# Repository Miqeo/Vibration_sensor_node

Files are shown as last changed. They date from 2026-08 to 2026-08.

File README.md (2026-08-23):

# Vibration sensor node

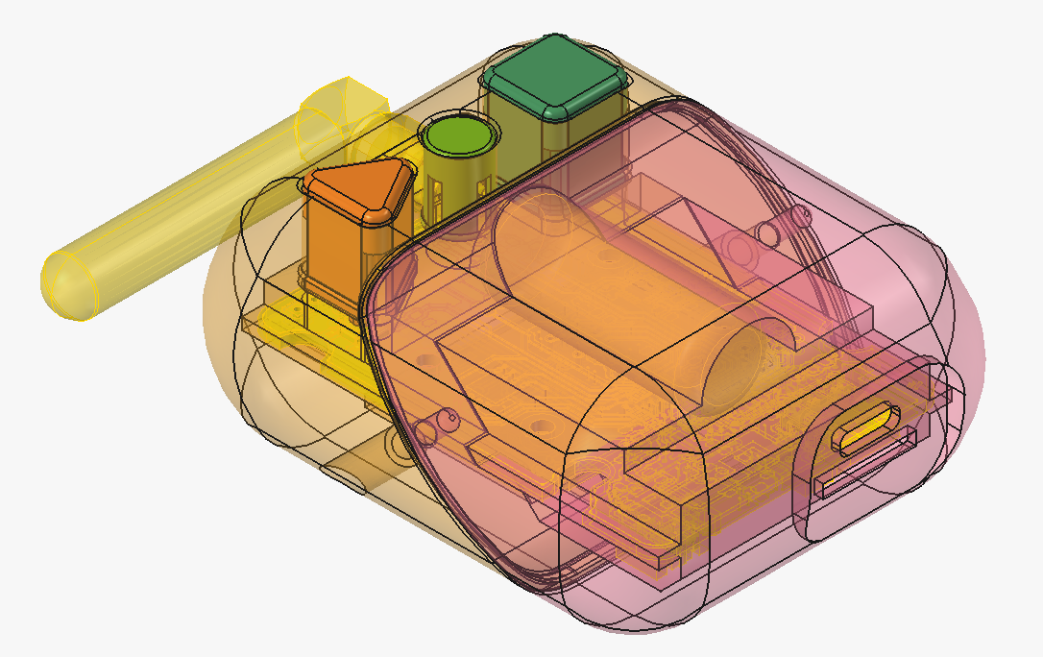
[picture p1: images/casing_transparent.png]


## Motivation

Since my first endeavour into PCB and CAD design, I have always wanted to create something from start to finish. This was possible with one of the previous projects I was a part of, where there was a need to make a Raspberry Pi HAT, the software to run with it, and the corresponding casing.

As that project came to a close, I wanted to make use of my time and extend my knowledge with this initiative to make something useful and to test the capabilities of FOSS software such as Freecad and Kicad.

This culminated in the amalgamation of sensors, storage, comms, and compute that can be called a “node” for the distributed sensor system.

As this is a work in progress, and the exact use might change with time, I do not want to point towards the problem it might, in the future, solve. The time-synchronised system of this kind may be used in places where other, physically connected or remote nodes are used now.

## Future capabilities

The planned capabilities of the node are to autonomously save vibration data and synchronize it in time with other nodes using a wireless link. The nodes equipped with the 3-axis gyroscope would also be able to track changes in rotation. 

## System elements

The system makes use of the small cyllindrical battery, repurposed from an ellectrical cigarette. The main computation is done by the STM32 microcontroller, which has access to the onboard accrellerometer-gyroscope combo and an extensible accelerometer via a board-to-board connector. The microcontroller is connected to the outside world via the wireless module and usb 2.0 via USB-C, which also acts as the charger for the unit. The data collected can be stored on the external SD card or the soldered-on QSPI flash.

[Here is the schematic document of the controller board](/pcb/accel_controller_schematic.pdf)

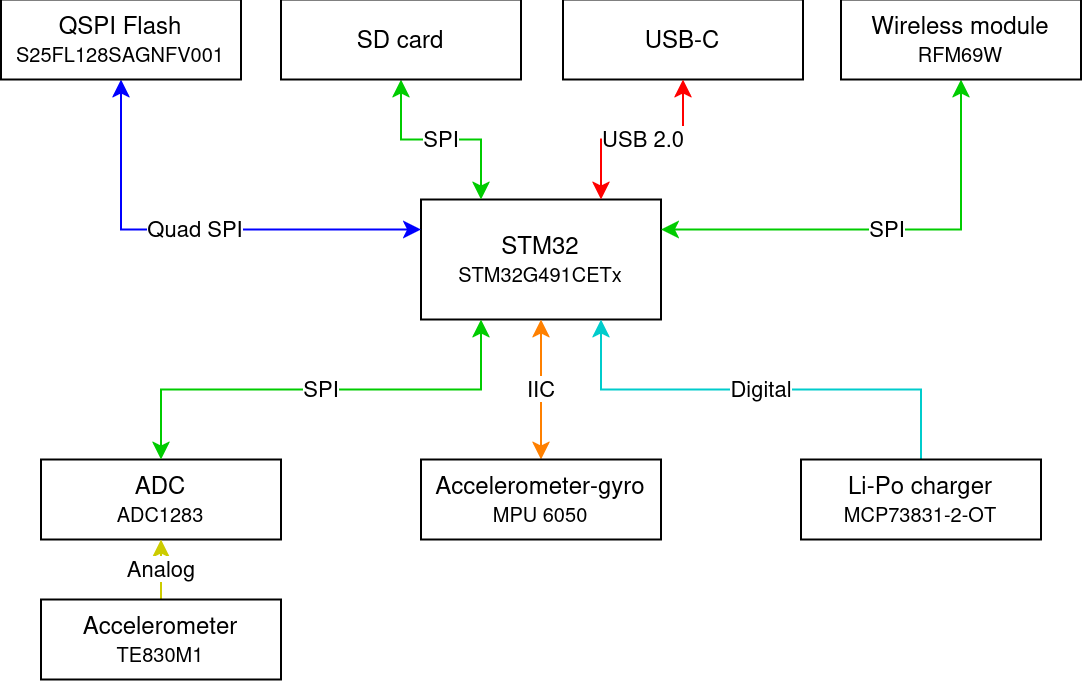
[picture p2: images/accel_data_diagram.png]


*Data flow of the system*

## Fabrication

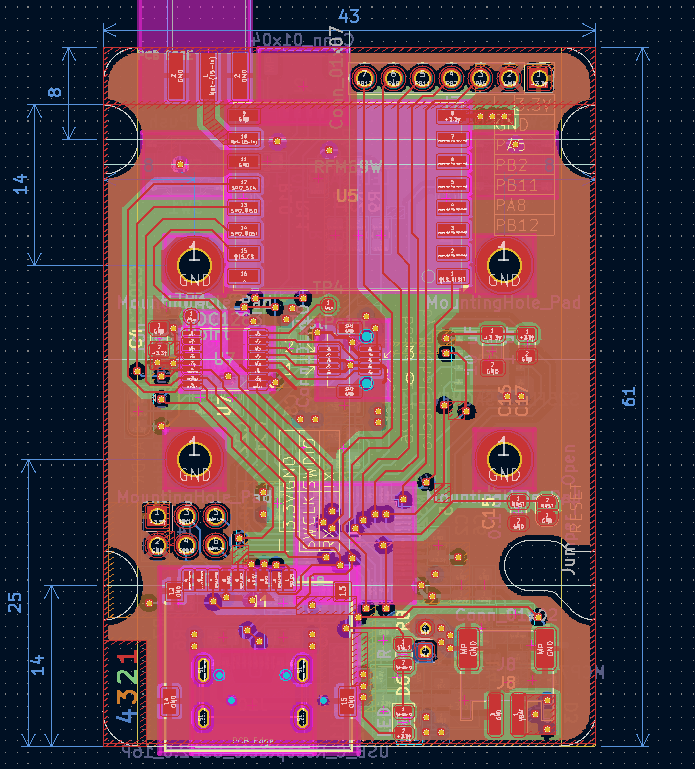
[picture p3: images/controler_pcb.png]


*The main controller PCB*

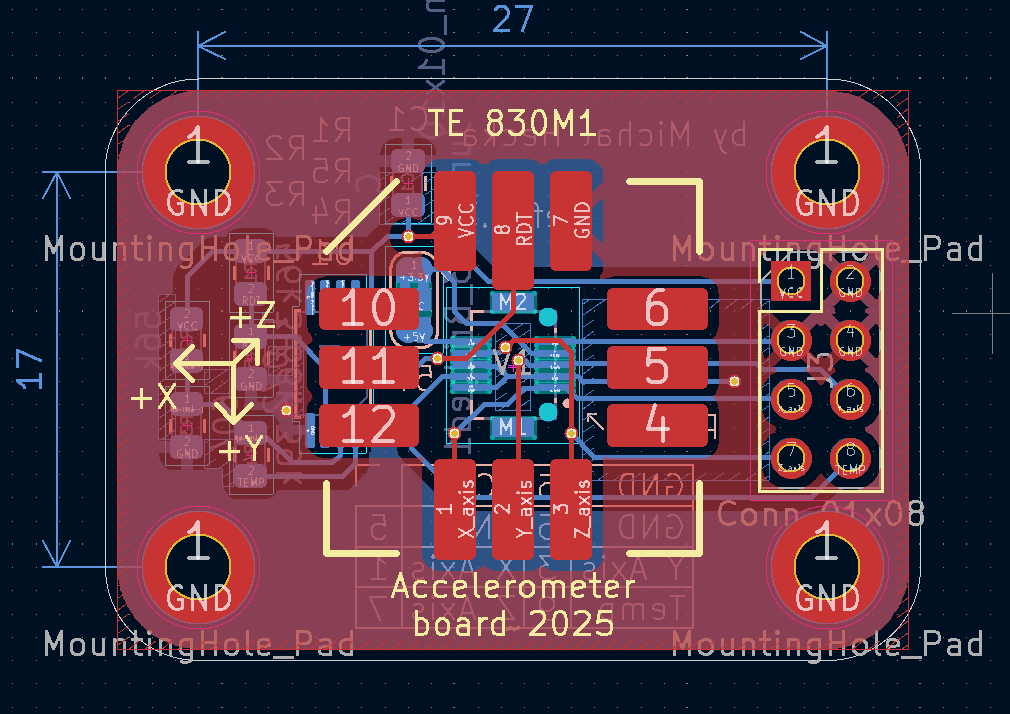
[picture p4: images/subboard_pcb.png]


*A sensor sub-board connected via a board-to-board connector*



*Model of the the sensor casing*

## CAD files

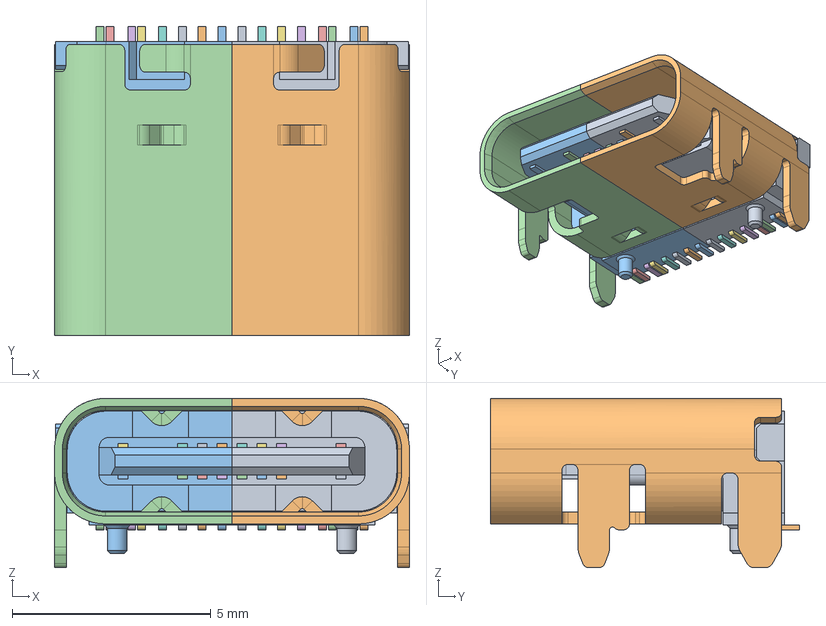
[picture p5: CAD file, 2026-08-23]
cad/gtc_usb4105.FCStd
8.94 x 7.78 x 4.26 mm
USB_C_Receptacle_16P_TopMnt_Horizontal_GCT_USB4105-xx-A
USB_C_Receptacle_16P_TopMnt_Horizontal_GCT_USB4105-xx-A001
USB_C_Receptacle_16P_TopMnt_Horizontal_GCT_USB4105-xx-A002
USB_C_Receptacle_16P_TopMnt_Horizontal_GCT_USB4105-xx-A003
USB_C_Receptacle_16P_TopMnt_Horizontal_GCT_USB4105-xx-A004
USB_C_Receptacle_16P_TopMnt_Horizontal_GCT_USB4105-xx-A005
USB_C_Receptacle_16P_TopMnt_Horizontal_GCT_USB4105-xx-A006
USB_C_Receptacle_16P_TopMnt_Horizontal_GCT_USB4105-xx-A007
USB_C_Receptacle_16P_TopMnt_Horizontal_GCT_USB4105-xx-A008
USB_C_Receptacle_16P_TopMnt_Horizontal_GCT_USB4105-xx-A009
USB_C_Receptacle_16P_TopMnt_Horizontal_GCT_USB4105-xx-A010
USB_C_Receptacle_16P_TopMnt_Horizontal_GCT_USB4105-xx-A011
USB_C_Receptacle_16P_TopMnt_Horizontal_GCT_USB4105-xx-A012
USB_C_Receptacle_16P_TopMnt_Horizontal_GCT_USB4105-xx-A013
USB_C_Receptacle_16P_TopMnt_Horizontal_GCT_USB4105-xx-A014
USB_C_Receptacle_16P_TopMnt_Horizontal_GCT_USB4105-xx-A015
USB_C_Receptacle_16P_TopMnt_Horizontal_GCT_USB4105-xx-A016
USB_C_Receptacle_16P_TopMnt_Horizontal_GCT_USB4105-xx-A017
USB_C_Receptacle_16P_TopMnt_Horizontal_GCT_USB4105-xx-A018
USB_C_Receptacle_16P_TopMnt_Horizontal_GCT_USB4105-xx-A019
USB_C_Receptacle_16P_TopMnt_Horizontal_GCT_USB4105-xx-A020
USB_C_Receptacle_16P_TopMnt_Horizontal_GCT_USB4105-xx-A021
USB_C_Receptacle_16P_TopMnt_Horizontal_GCT_USB4105-xx-A022
USB_C_Receptacle_16P_TopMnt_Horizontal_GCT_USB4105-xx-A023
USB_C_Receptacle_16P_TopMnt_Horizontal_GCT_USB4105-xx-A024
USB_C_Receptacle_16P_TopMnt_Horizontal_GCT_USB4105-xx-A025
USB_C_Receptacle_16P_TopMnt_Horizontal_GCT_USB4105-xx-A026
USB_C_Receptacle_16P_TopMnt_Horizontal_GCT_USB4105-xx-A027
USB_C_Receptacle_16P_TopMnt_Horizontal_GCT_USB4105-xx-A028
USB_C_Receptacle_16P_TopMnt_Horizontal_GCT_USB4105-xx-A029
USB_C_Receptacle_16P_TopMnt_Horizontal_GCT_USB4105-xx-A030
USB_C_Receptacle_16P_TopMnt_Horizontal_GCT_USB4105-xx-A031
USB_C_Receptacle_16P_TopMnt_Horizontal_GCT_USB4105-xx-A032
USB_C_Receptacle_16P_TopMnt_Horizontal_GCT_USB4105-xx-A033
USB_C_Receptacle_16P_TopMnt_Horizontal_GCT_USB4105-xx-A034
USB_C_Receptacle_16P_TopMnt_Horizontal_GCT_USB4105-xx-A035

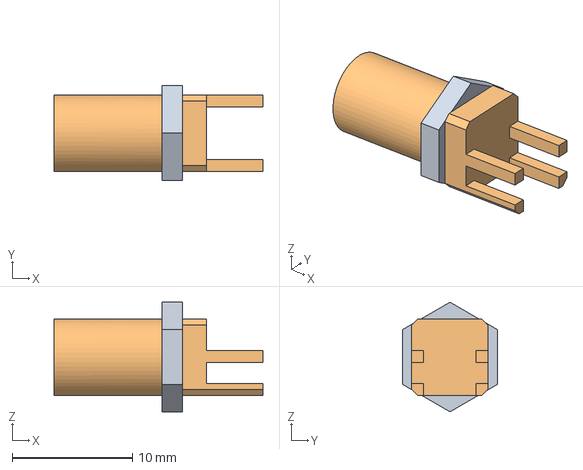
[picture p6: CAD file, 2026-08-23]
cad/sma_connector.FCStd
17.4 x 7.90 x 9.12 mm

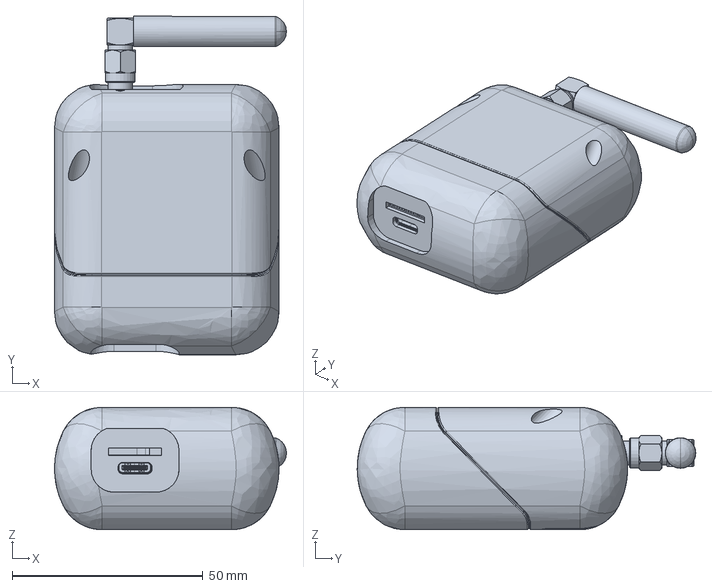
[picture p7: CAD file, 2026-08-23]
cad/casing_drawing.FCStd
60.7 x 88.6 x 32.0 mm

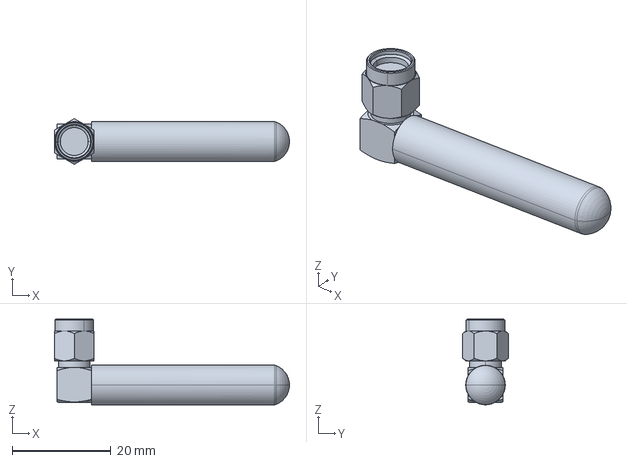
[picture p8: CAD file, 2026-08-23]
cad/ism_antenna.FCStd
47.5 x 9.24 x 17.3 mm

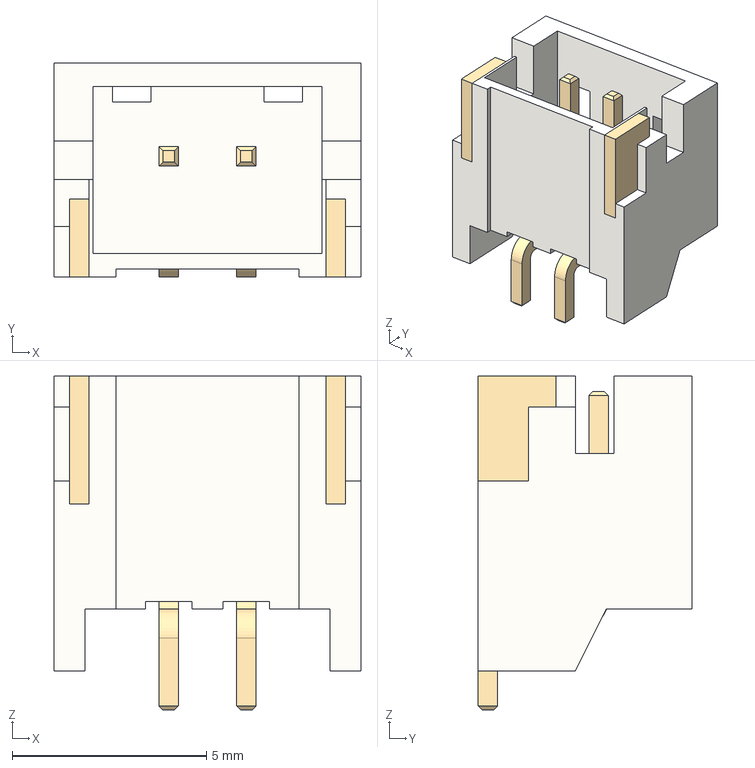
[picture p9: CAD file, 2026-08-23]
cad/S2B-PH-SM4-TB.stp
7.90 x 5.50 x 8.60 mm

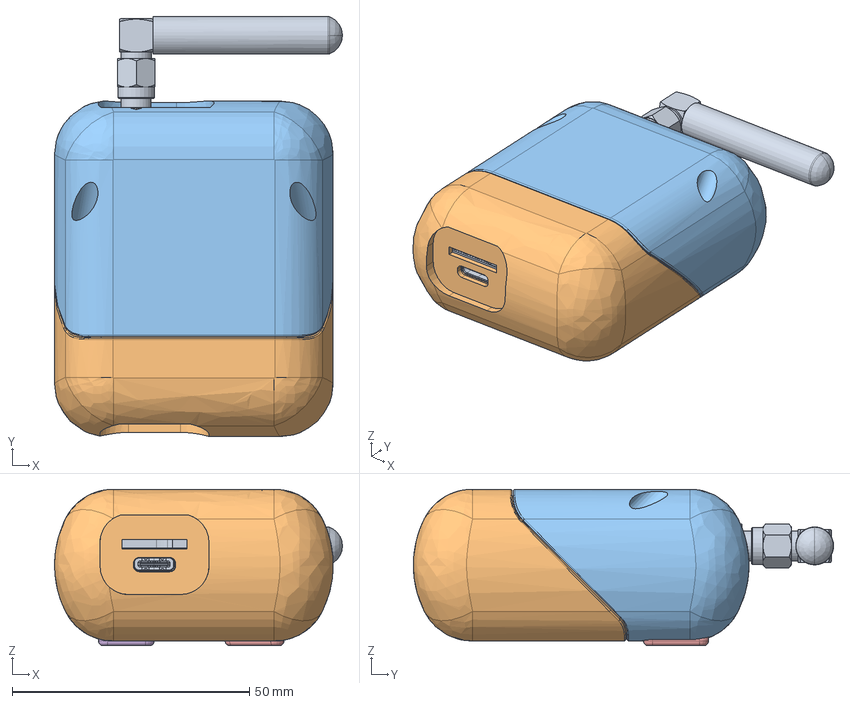
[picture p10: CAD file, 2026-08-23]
cad/Casing.FCStd
60.7 x 88.6 x 33.0 mm
Binder
Case mounted lower
Case upper buttons
Light diffuser
Triangle button
Square button

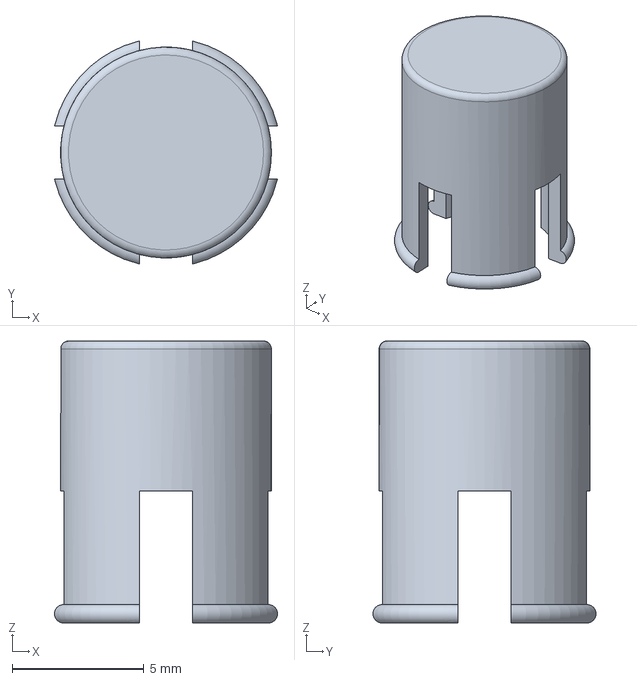
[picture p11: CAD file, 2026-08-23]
cad/Light_diffuser.FCStd
8.47 x 8.47 x 10.7 mm

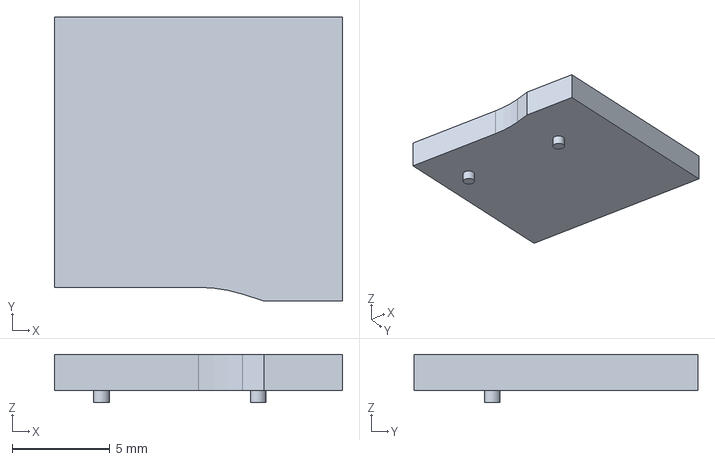
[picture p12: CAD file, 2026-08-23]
cad/sd_card_slot.FCStd
14.7 x 14.5 x 2.45 mm

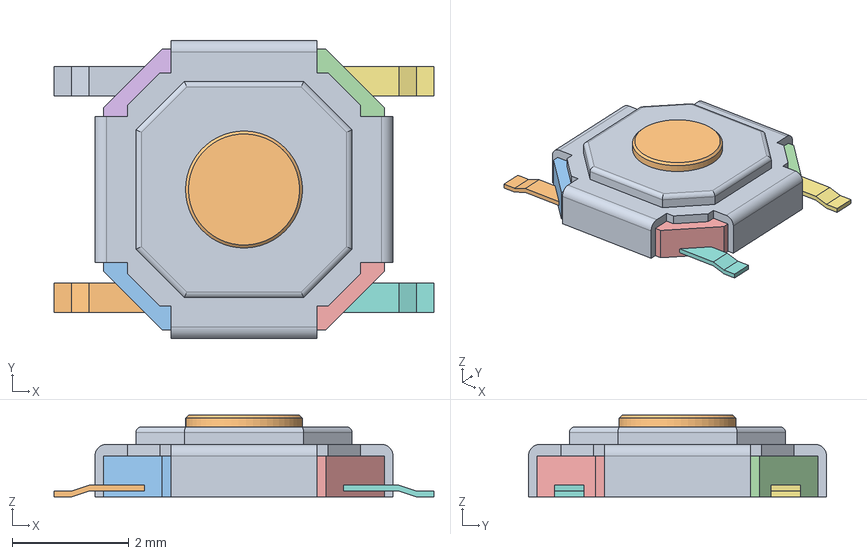
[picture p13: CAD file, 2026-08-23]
cad/smd_button.FCStd
6.50 x 5.10 x 1.40 mm
TS-1187A v2
TS-1187A v001
TS-1187A v002
TS-1187A v003
TS-1187A v004
TS-1187A v005
TS-1187A v006
TS-1187A v007
TS-1187A v008
TS-1187A v009

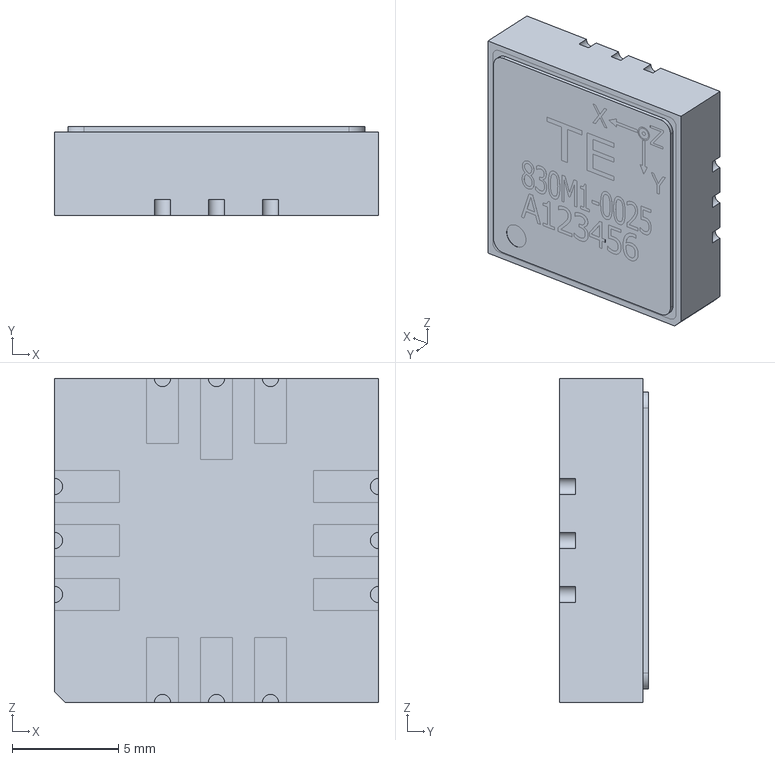
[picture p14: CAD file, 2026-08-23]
cad/c-20011422-00-b-3d.stp
15.2 x 4.20 x 15.2 mm

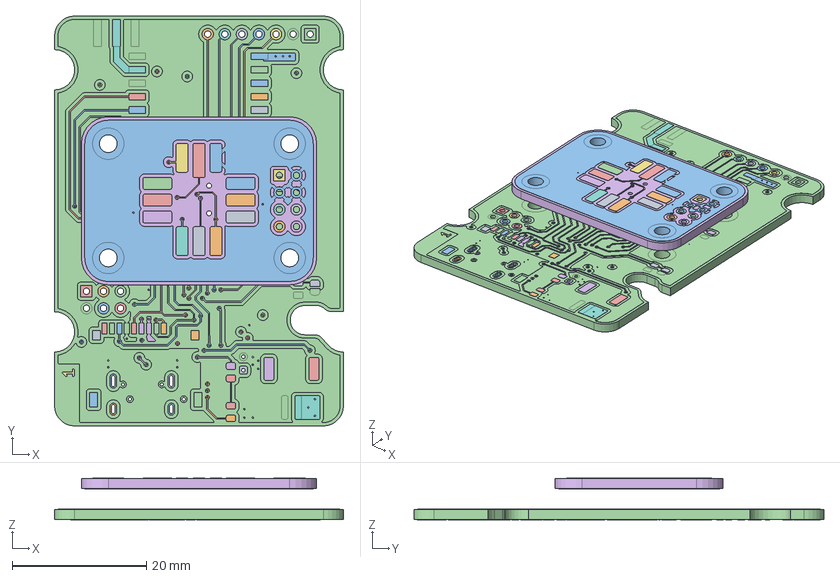
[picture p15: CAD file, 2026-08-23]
cad/electronics.FCStd
43.0 x 61.0 x 6.18 mm
accelerometer_subboard_copper
accelerometer_subboard_copper001
accelerometer_subboard_copper002
accelerometer_subboard_copper003
accelerometer_subboard_copper004
accelerometer_subboard_copper005
accelerometer_subboard_copper006
accelerometer_subboard_copper007
accelerometer_subboard_copper008
accelerometer_subboard_copper009
accelerometer_subboard_copper010
accelerometer_subboard_copper011
accelerometer_subboard_copper012
accelerometer_subboard_copper013
accelerometer_subboard_copper014
accelerometer_subboard_copper015
accelerometer_subboard_copper016
accelerometer_subboard_copper017
accelerometer_subboard_copper018
accelerometer_subboard_copper019
accelerometer_subboard_copper020
accelerometer_subboard_PCB
accelerometer_controller_copper341
accelerometer_controller_copper342
accelerometer_controller_copper343
accelerometer_controller_copper344
accelerometer_controller_copper345
accelerometer_controller_copper346
accelerometer_controller_copper347
accelerometer_controller_copper348
accelerometer_controller_copper349
accelerometer_controller_copper350
accelerometer_controller_copper351
accelerometer_controller_copper352
accelerometer_controller_copper353
accelerometer_controller_copper354
accelerometer_controller_copper355
accelerometer_controller_copper356
accelerometer_controller_copper357
accelerometer_controller_copper358
accelerometer_controller_copper359
accelerometer_controller_copper360
accelerometer_controller_copper361
accelerometer_controller_copper362
accelerometer_controller_copper363
accelerometer_controller_copper364
accelerometer_controller_copper365
accelerometer_controller_copper366
accelerometer_controller_copper367
accelerometer_controller_copper368
accelerometer_controller_copper369
accelerometer_controller_copper370
accelerometer_controller_copper371
accelerometer_controller_copper372
accelerometer_controller_copper373
accelerometer_controller_copper374
accelerometer_controller_copper375
accelerometer_controller_copper376
accelerometer_controller_copper377
accelerometer_controller_copper378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

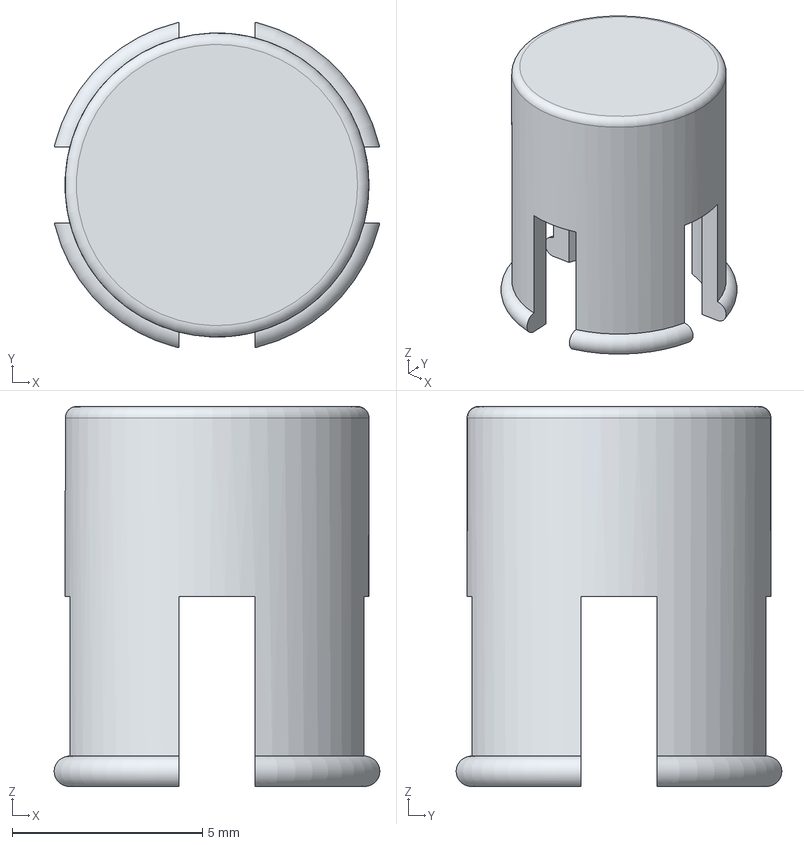
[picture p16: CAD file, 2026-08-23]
cad/Light_diffuser-Body.step
8.57 x 8.57 x 10.0 mm

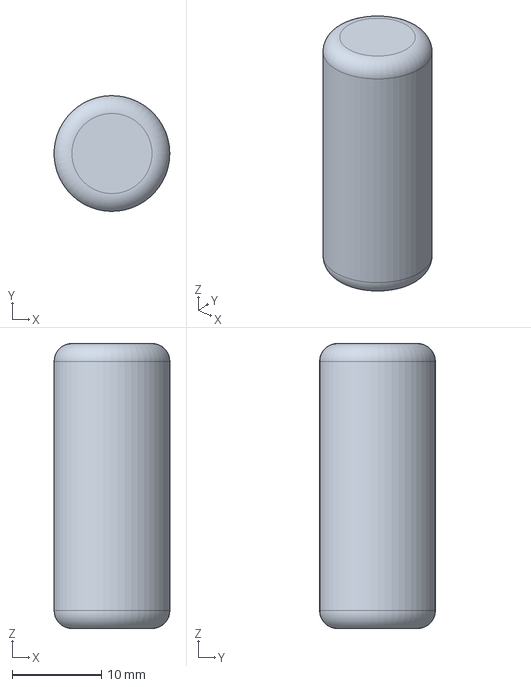
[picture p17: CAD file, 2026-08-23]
cad/battery.FCStd
13.0 x 13.0 x 32.0 mm

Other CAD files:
cad/jst_batt.FCStd
cad/c-2195892-1-1-3d.stp
cad/USB_C_Receptacle_GCT_USB4105-xx-A_16P_TopMnt_Horizontal.step
cad/TS-1187A.step
cad/triaxial_accelerometer.FCStd

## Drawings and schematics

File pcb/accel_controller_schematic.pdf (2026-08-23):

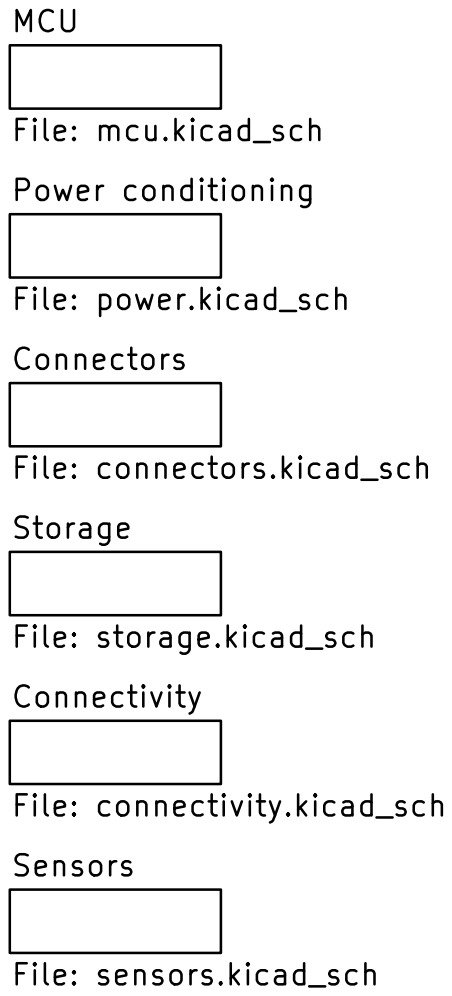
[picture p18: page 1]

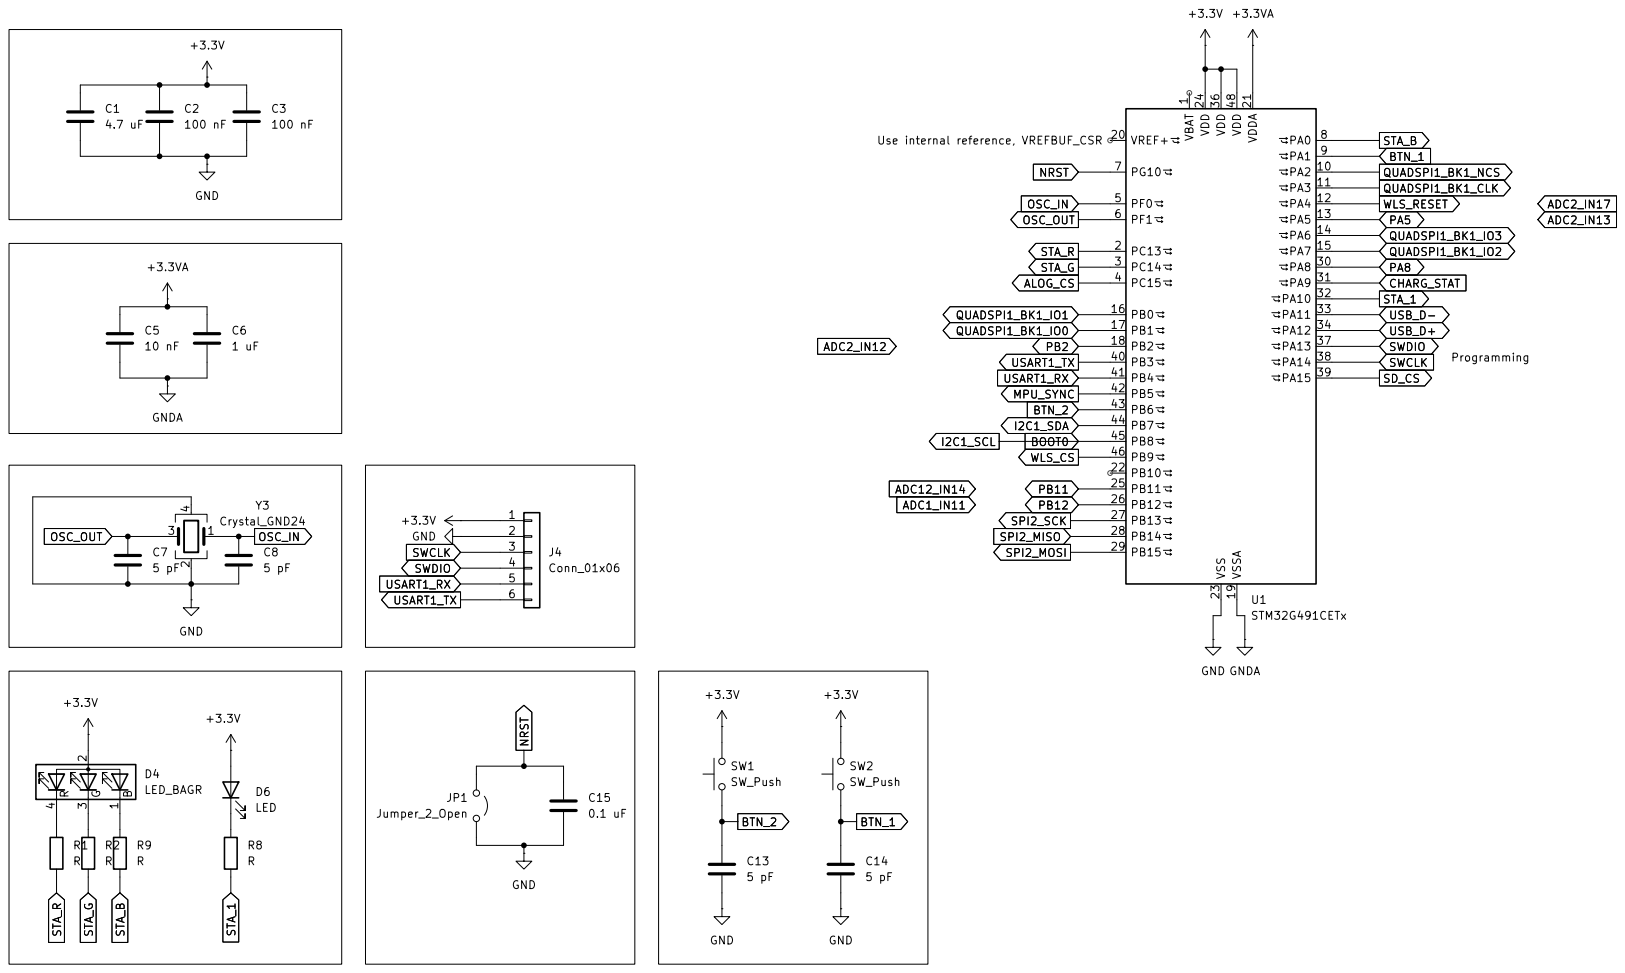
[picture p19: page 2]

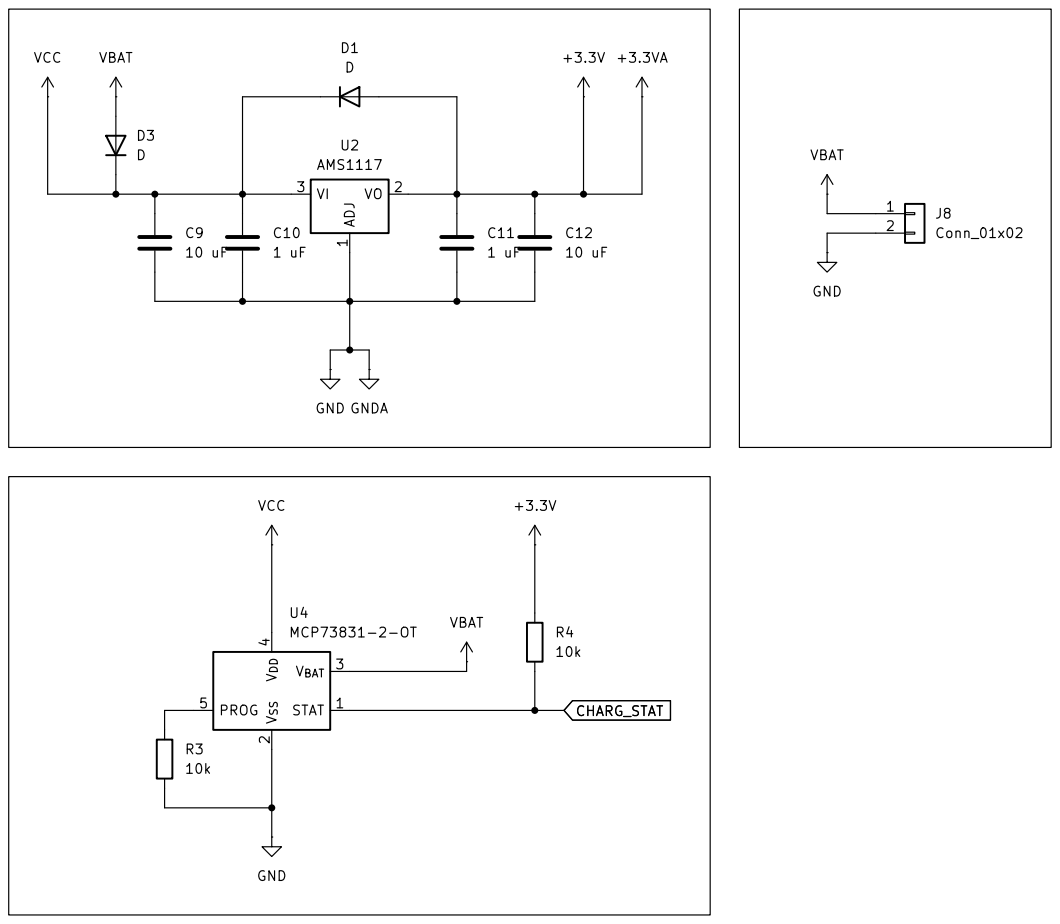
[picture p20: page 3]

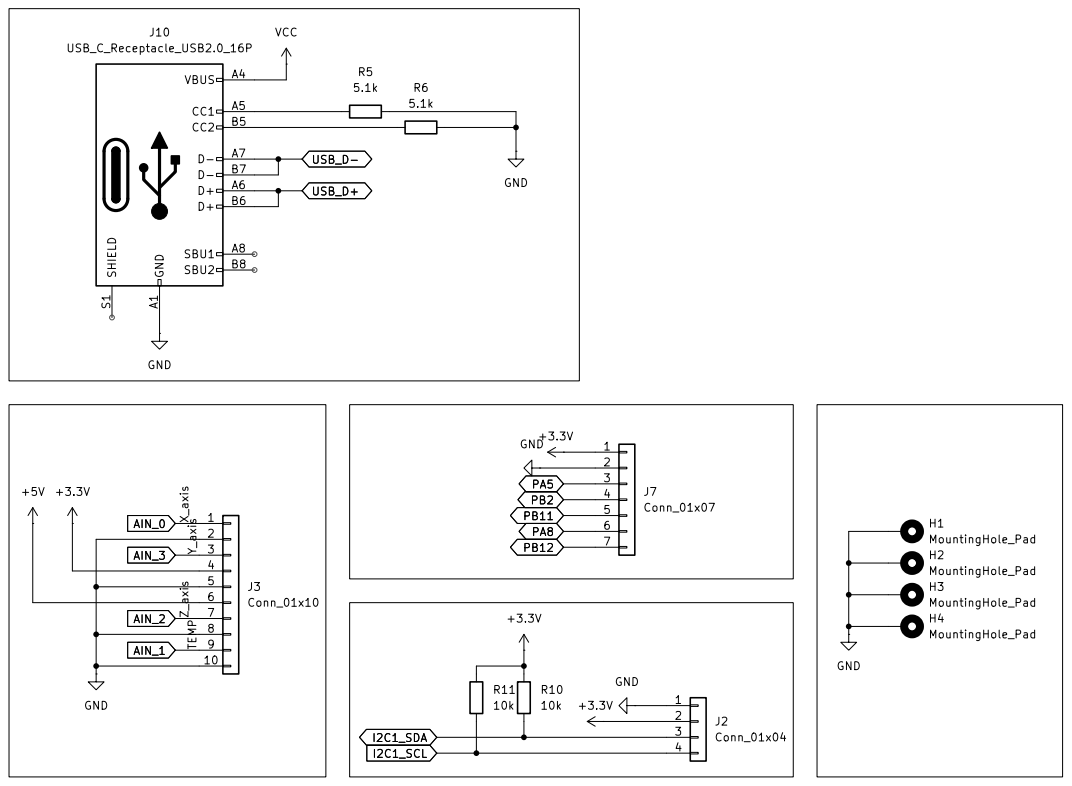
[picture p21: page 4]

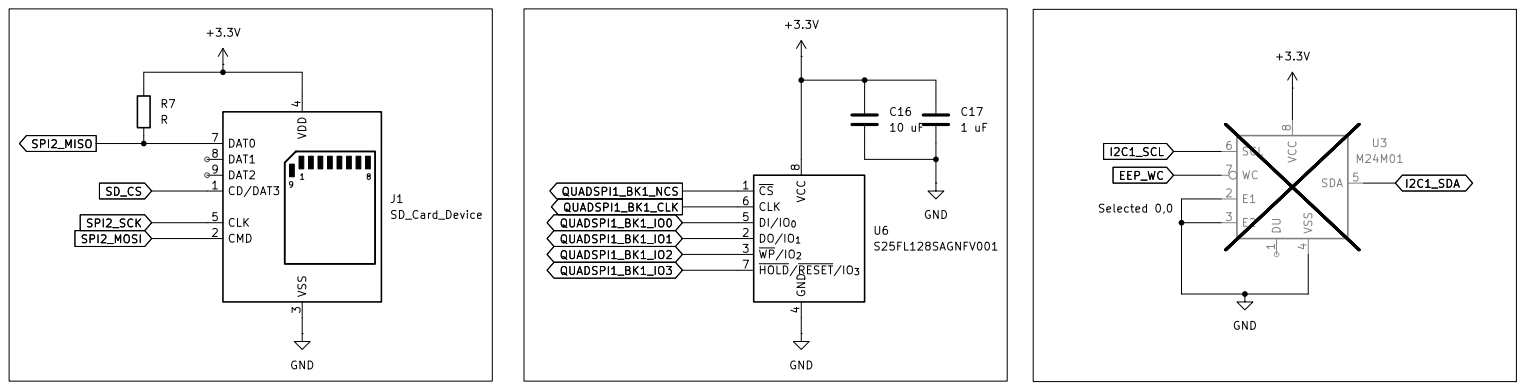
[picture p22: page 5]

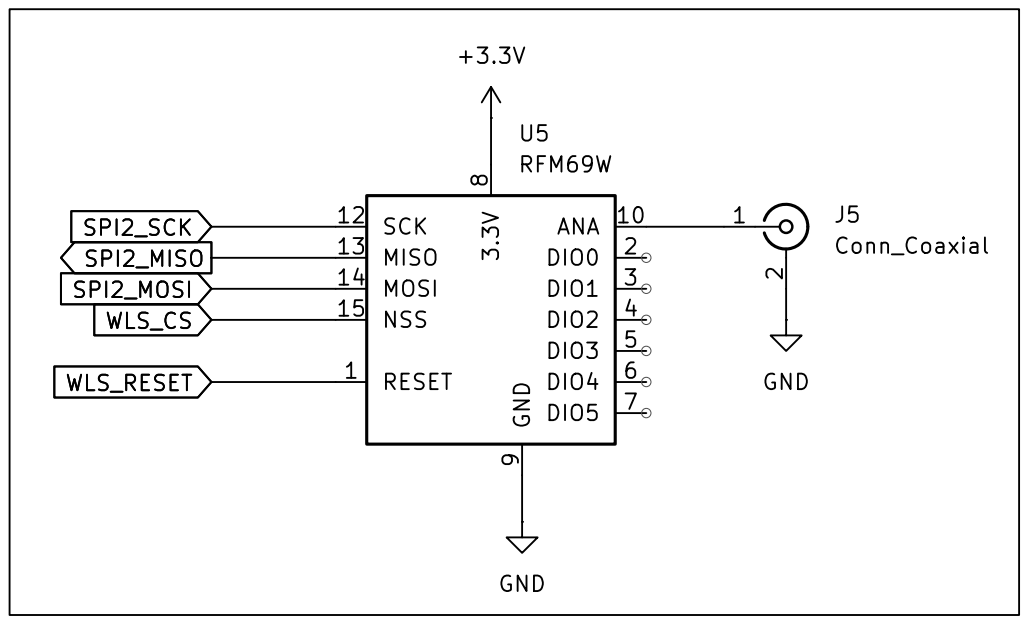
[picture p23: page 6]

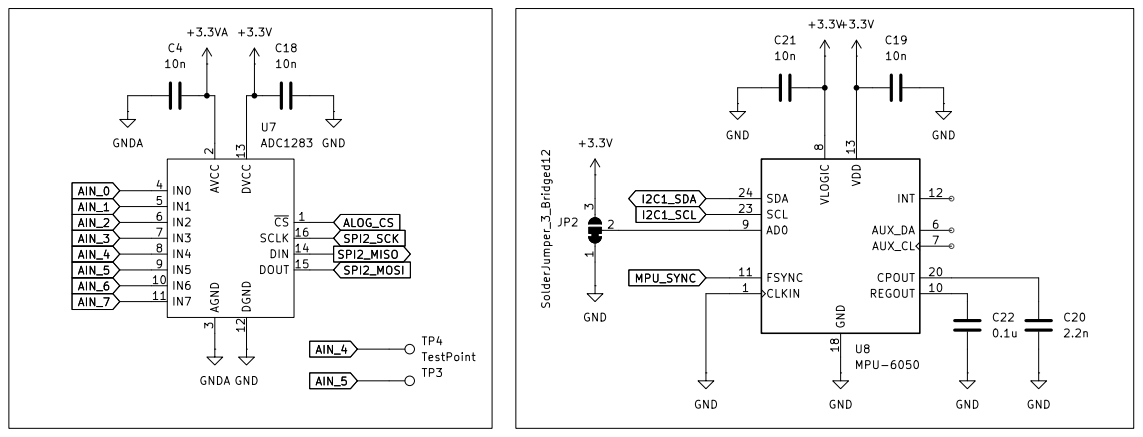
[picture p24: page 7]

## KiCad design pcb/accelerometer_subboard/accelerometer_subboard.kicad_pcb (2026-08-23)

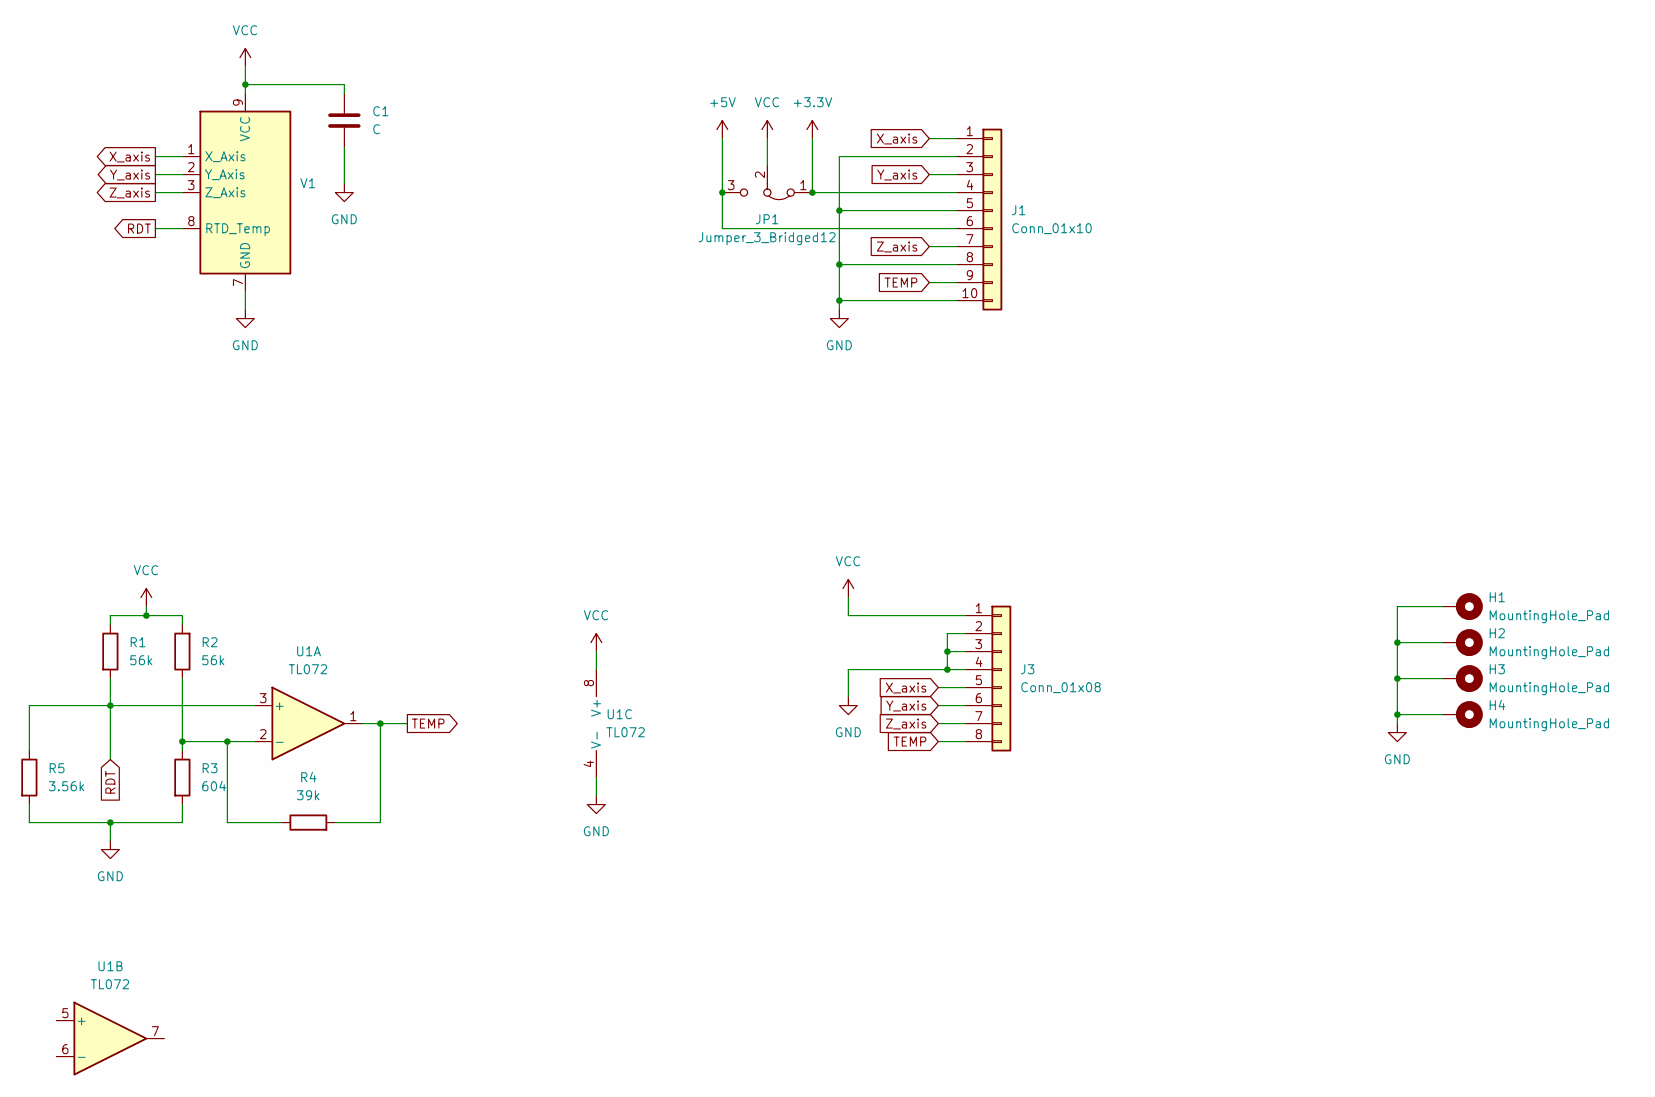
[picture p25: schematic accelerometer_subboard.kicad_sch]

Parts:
C1: C; C_0805_2012Metric
H1, H2, H3, H4: MountingHole_Pad; MountingHole_2.7mm_M2.5_DIN965_Pad
J1: Conn_01x10; AMPHENOL_10132798-011100LF
J3: Conn_01x08; PinHeader_2x04_P2.54mm_Vertical
JP1: Jumper_3_Bridged12; SolderJumper-3_P1.3mm_Bridged2Bar12_RoundedPad1.0x1.5mm
R1, R2: 56k; R_0805_2012Metric
R3: 604; R_0805_2012Metric
R4: 39k; R_0805_2012Metric
R5: 3.56k; R_0805_2012Metric
U1: TL072; TSSOP-8_4.4x3mm_P0.65mm
V1: TE_Connectivity_830M1

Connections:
+3.3V: J1.4, JP1.1 (A)
+5V: J1.6, JP1.3 (B)
GND: C1.2, H1.1, H2.1, H3.1, H4.1, J1.2, J1.5, J1.8, J1.10, J3.2, J3.3, J3.4, R3.2, R5.2, U1.4 (V-), V1.7 (GND)
unnamed: R2.1, R3.1, R4.1, U1.2 (-)
RDT: R1.2, R5.1, U1.3 (+), V1.8 (RTD_Temp)
TEMP: J1.9, J3.8, R4.2, U1.1
VCC: C1.1, J3.1, JP1.2 (C), R1.1, R2.2, U1.8 (V+), V1.9 (VCC)
X_axis: J1.1, J3.5, V1.1 (X_Axis)
Y_axis: J1.3, J3.6, V1.2 (Y_Axis)
Z_axis: J1.7, J3.7, V1.3 (Z_Axis)

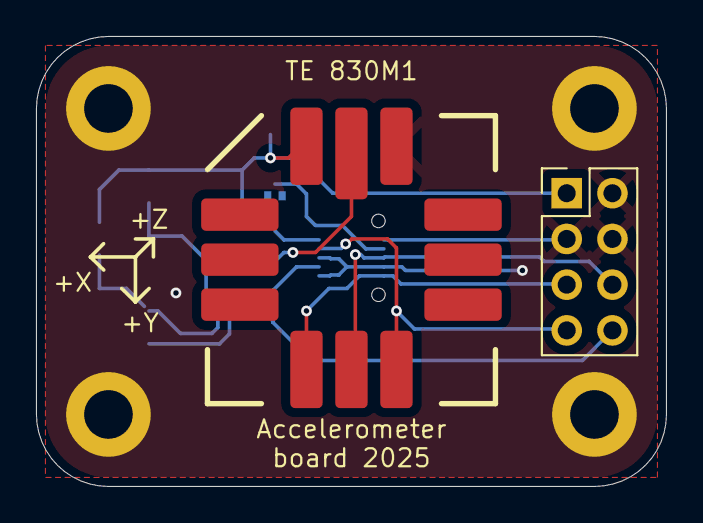
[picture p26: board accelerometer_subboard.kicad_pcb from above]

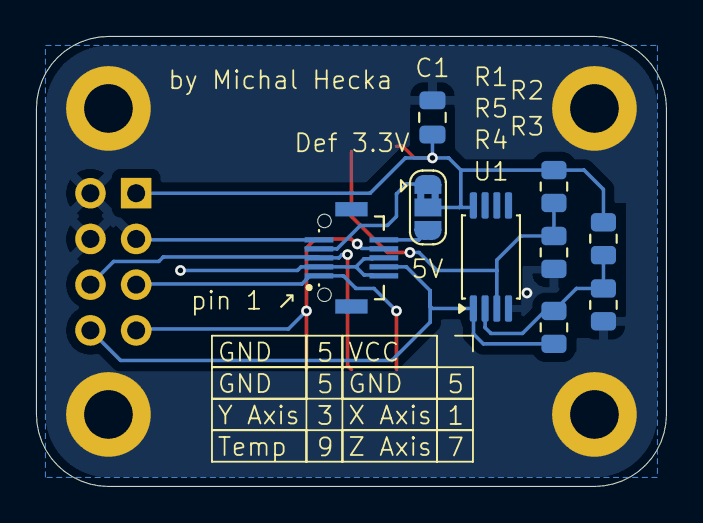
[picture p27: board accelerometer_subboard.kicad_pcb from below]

Board: 2 copper layers, 35.0 x 25.0 mm, 15 parts (9 on the bottom side), 10 nets.

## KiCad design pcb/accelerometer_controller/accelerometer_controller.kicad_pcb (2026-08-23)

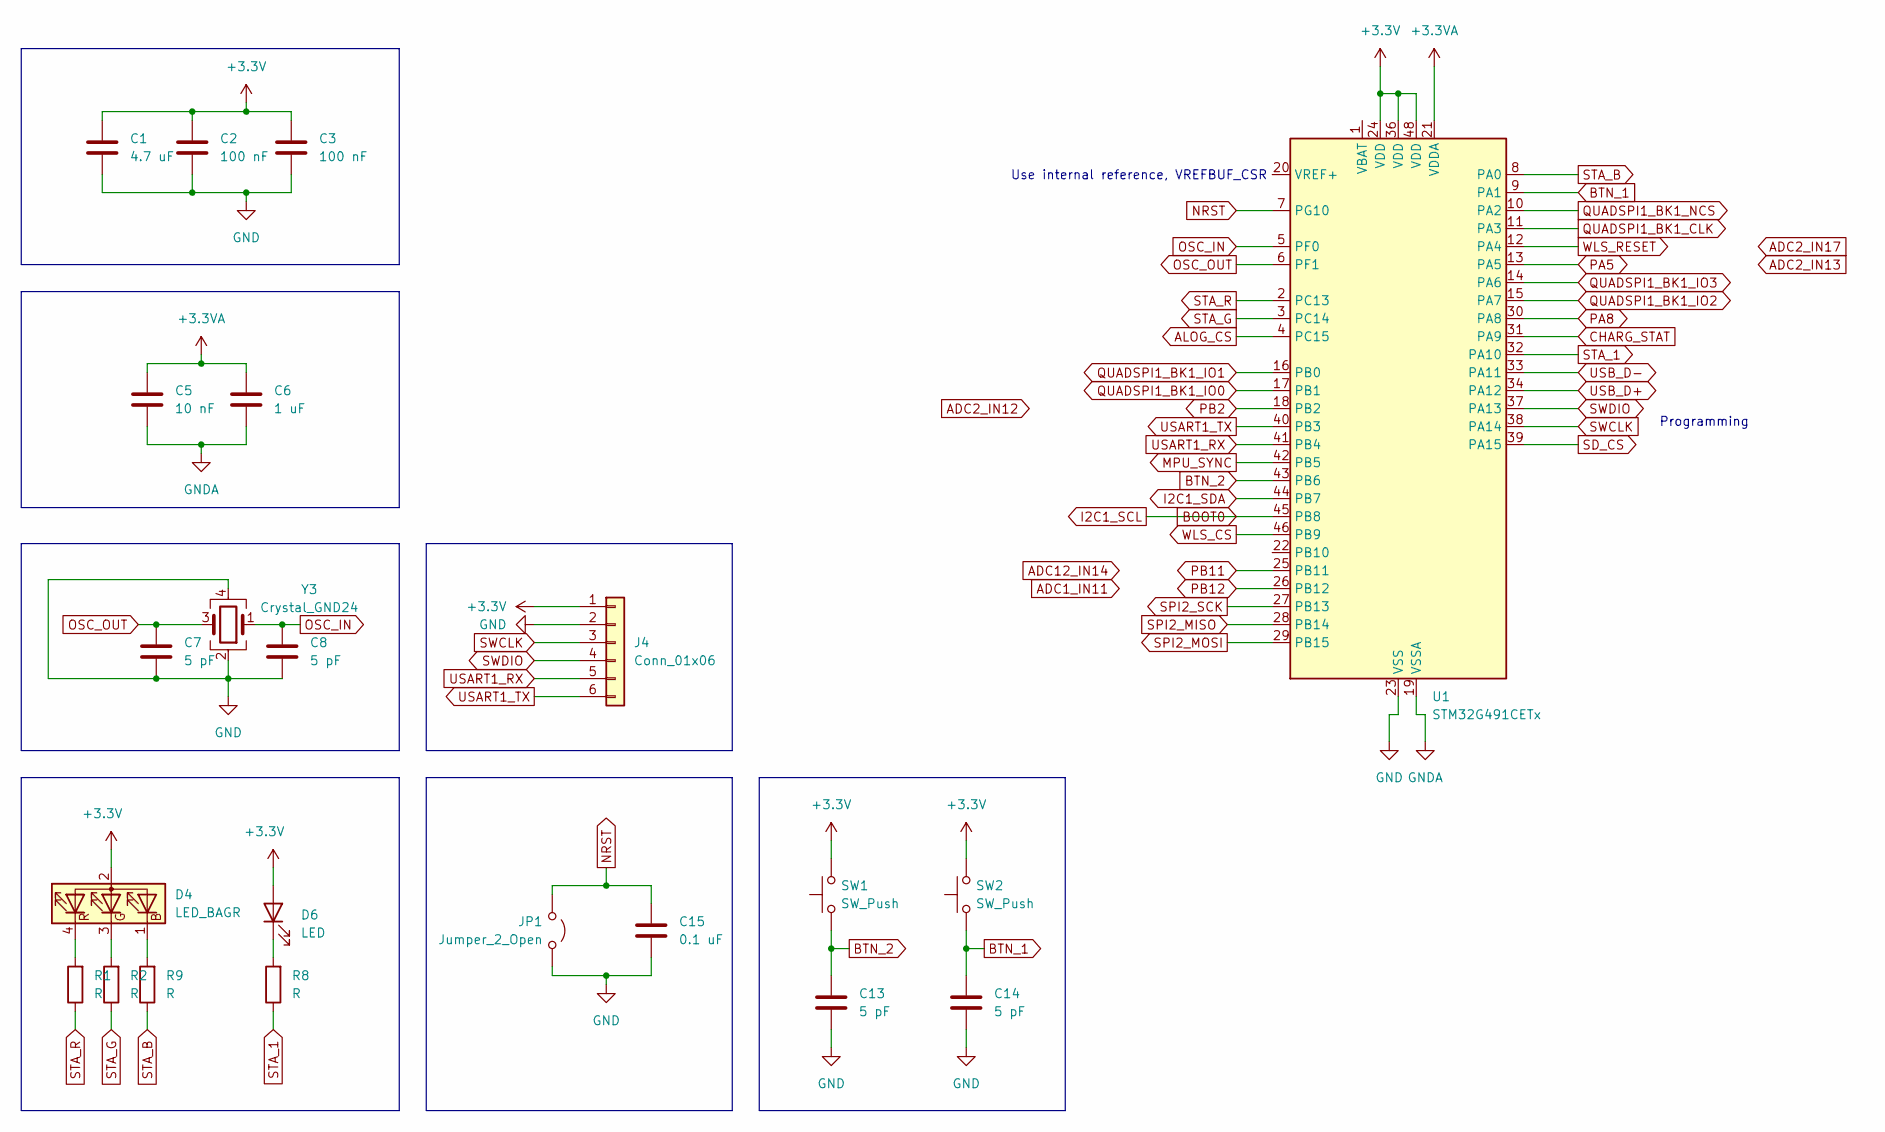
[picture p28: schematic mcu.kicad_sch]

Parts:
C1: 4.7 uF; C_0805_2012Metric
C2, C3: 100 nF; C_0805_2012Metric
C5: 10 nF; C_0805_2012Metric
C6: 1 uF; C_0805_2012Metric
C7, C8, C13, C14: 5 pF; C_0805_2012Metric
C15: 0.1 uF; C_0805_2012Metric
D4: LED_BAGR; OSTB0805C1E-A-0.8T
D6: LED; LED_0805_2012Metric
J4: Conn_01x06; PinHeader_2x03_P2.54mm_Vertical
JP1: Jumper_2_Open; SolderJumper-2_P1.3mm_Open_RoundedPad1.0x1.5mm
R1, R2, R8, R9: R; R_0805_2012Metric
SW1, SW2: SW_Push; SW_Push_1P1T_XKB_TS-1187A
U1: STM32G491CETx; LQFP-48_7x7mm_P0.5mm
Y3: Crystal_GND24; Crystal_SMD_3225-4Pin_3.2x2.5mm

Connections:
+3.3V: C1.1, C2.1, C3.1, C5.1, C6.1, D4.2 (A), D6.2 (A), J4.1, SW1.2, SW2.2, U1.21 (VDDA), U1.24 (VDD), U1.36 (VDD), U1.48 (VDD); also elsewhere on the board
ALOG_CS: U1.4 (PC15); also elsewhere on the board
BOOT0: U1.45 (PB8); also elsewhere on the board
BTN_1: C14.1, SW2.1, U1.9 (PA1)
BTN_2: C13.1, SW1.1, U1.43 (PB6)
CHARG_STAT: U1.31 (PA9); also elsewhere on the board
GND: C1.2, C2.2, C3.2, C5.2, C6.2, C7.2, C8.2, C13.2, C14.2, C15.2, J4.2, JP1.1 (A), U1.19 (VSSA), U1.23 (VSS), U1.35 (VSS), U1.47 (VSS), Y3.2, Y3.4; also elsewhere on the board
I2C1_SDA: U1.44 (PB7); also elsewhere on the board
MPU_SYNC: U1.42 (PB5); also elsewhere on the board
NRST: C15.1, JP1.2 (B), U1.7 (PG10)
unnamed: D4.1 (BK), R9.2
unnamed: D4.3 (GK), R2.2
unnamed: D4.4 (RK), R1.2
unnamed: D6.1 (K), R8.2
OSC_IN: C8.1, U1.5 (PF0), Y3.1
OSC_OUT: C7.1, U1.6 (PF1), Y3.3
PA5: U1.13 (PA5); also elsewhere on the board
PA8: U1.30 (PA8); also elsewhere on the board
PB2: U1.18 (PB2); also elsewhere on the board
PB11: U1.25 (PB11); also elsewhere on the board
PB12: U1.26 (PB12); also elsewhere on the board
QUADSPI1_BK1_CLK: U1.11 (PA3); also elsewhere on the board
QUADSPI1_BK1_IO0: U1.17 (PB1); also elsewhere on the board
QUADSPI1_BK1_IO1: U1.16 (PB0); also elsewhere on the board
QUADSPI1_BK1_IO2: U1.15 (PA7); also elsewhere on the board
QUADSPI1_BK1_IO3: U1.14 (PA6); also elsewhere on the board
QUADSPI1_BK1_NCS: U1.10 (PA2); also elsewhere on the board
SD_CS: U1.39 (PA15); also elsewhere on the board
SPI2_MISO: U1.28 (PB14); also elsewhere on the board
SPI2_MOSI: U1.29 (PB15); also elsewhere on the board
SPI2_SCK: U1.27 (PB13); also elsewhere on the board
STA_1: R8.1, U1.32 (PA10)
STA_B: R9.1, U1.8 (PA0)
STA_G: R2.1, U1.3 (PC14)
STA_R: R1.1, U1.2 (PC13)
SWCLK: J4.3, U1.38 (PA14)
SWDIO: J4.4, U1.37 (PA13)
USART1_RX: J4.5, U1.41 (PB4)
USART1_TX: J4.6, U1.40 (PB3)
USB_D+: U1.34 (PA12); also elsewhere on the board
USB_D-: U1.33 (PA11); also elsewhere on the board
WLS_CS: U1.46 (PB9); also elsewhere on the board
WLS_RESET: U1.12 (PA4); also elsewhere on the board

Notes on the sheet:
Use internal reference, VREFBUF_CSR
Programming

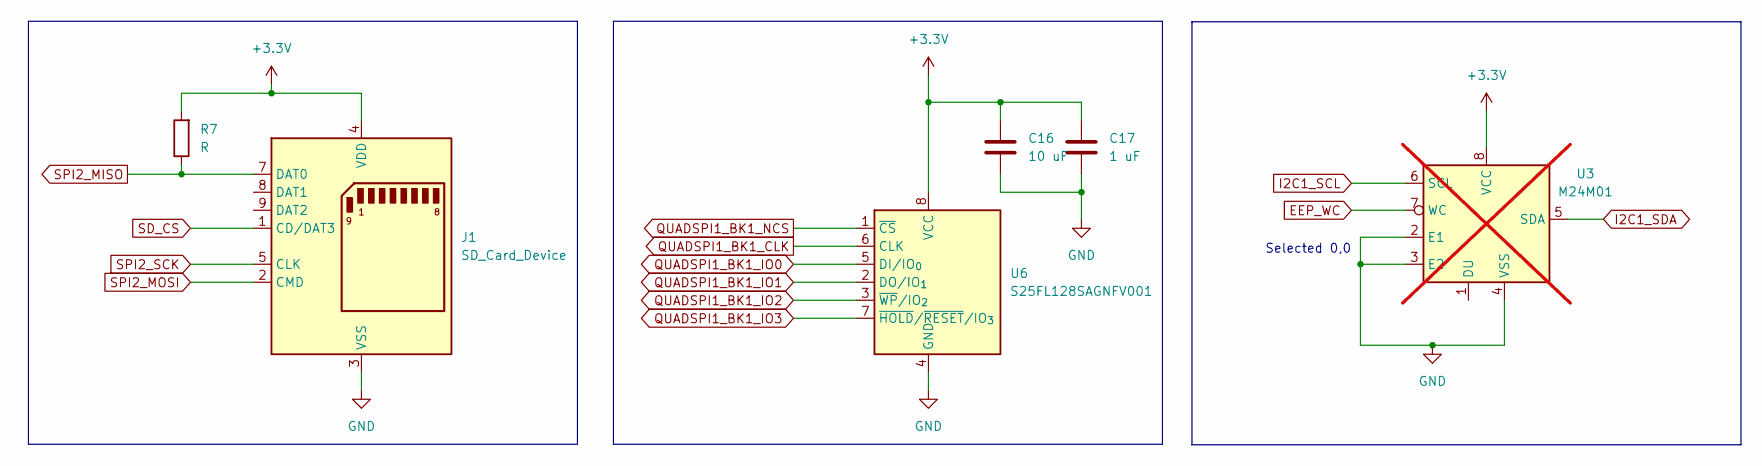
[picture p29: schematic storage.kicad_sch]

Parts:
C16: 10 uF; C_1206_3216Metric
C17: 1 uF; C_0805_2012Metric
J1: SD_Card_Device; 112J-TDAR-R01_ATT
R7: R; R_0805_2012Metric
U3: M24M01; SOIC-8_5.3x5.3mm_P1.27mm; not fitted
U6: S25FL128SAGNFV001; WSON-8-1EP_6x5mm_P1.27mm_EP3.4x4.3mm

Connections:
+3.3V: C16.1, C17.1, J1.4 (VDD), R7.2, U3.8 (VCC), U6.8 (VCC); also elsewhere on the board
GND: C16.2, C17.2, J1.3 (VSS), J1.6 (VSS), J1.12, J1.14, J1.15, U3.2 (E1), U3.3 (E2), U3.4 (VSS), U6.4 (GND); also elsewhere on the board
QUADSPI1_BK1_CLK: U6.6 (CLK); also elsewhere on the board
QUADSPI1_BK1_IO0: U6.5 (DI/IO_{0}); also elsewhere on the board
QUADSPI1_BK1_IO1: U6.2 (DO/IO_{1}); also elsewhere on the board
QUADSPI1_BK1_IO2: U6.3 (~WP/IO_{2}); also elsewhere on the board
QUADSPI1_BK1_IO3: U6.7 (~HOLD/~RESET/IO_{3}); also elsewhere on the board
QUADSPI1_BK1_NCS: U6.1 (~CS); also elsewhere on the board
SD_CS: J1.1 (CD/DAT3); also elsewhere on the board
SPI2_MISO: J1.7 (DAT0), R7.1; also elsewhere on the board
SPI2_MOSI: J1.2 (CMD); also elsewhere on the board
SPI2_SCK: J1.5 (CLK); also elsewhere on the board

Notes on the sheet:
Selected 0,0

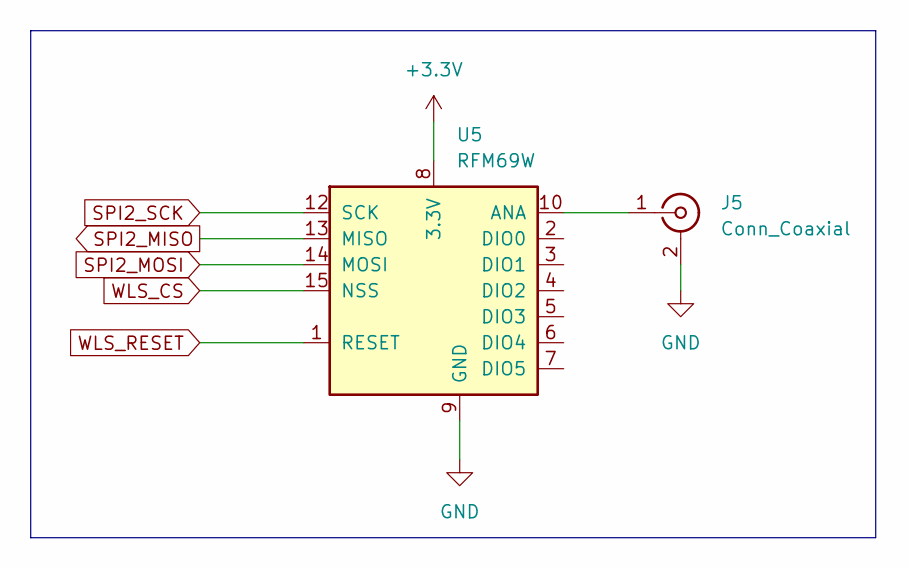
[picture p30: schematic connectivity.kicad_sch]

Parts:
J5: Conn_Coaxial; ADAMTECH_RF2-143-T-17-50-G
U5: RFM69W; HOPERF_RFM69HW

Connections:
+3.3V: U5.8 (3.3V); also elsewhere on the board
GND: J5.2 (Ext), U5.9 (GND), U5.11 (GND); also elsewhere on the board
unnamed: J5.1 (In), U5.10 (ANA)
SPI2_MISO: U5.13 (MISO); also elsewhere on the board
SPI2_MOSI: U5.14 (MOSI); also elsewhere on the board
SPI2_SCK: U5.12 (SCK); also elsewhere on the board
WLS_CS: U5.15 (NSS); also elsewhere on the board
WLS_RESET: U5.1 (RESET); also elsewhere on the board

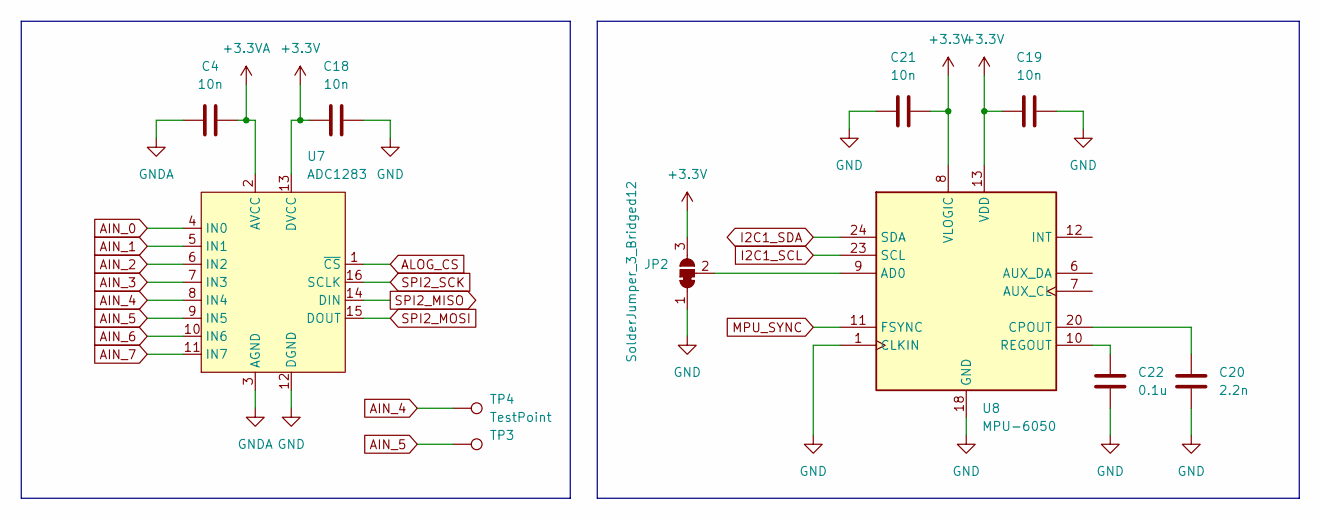
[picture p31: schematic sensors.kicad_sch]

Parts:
C4, C18, C19, C21: 10n; C_0805_2012Metric
C20: 2.2n; C_0805_2012Metric
C22: 0.1u; C_0805_2012Metric
JP2: SolderJumper_3_Bridged12; SolderJumper-3_P1.3mm_Bridged12_RoundedPad1.0x1.5mm
TP3, TP4: TestPoint; TestPoint_Pad_D1.0mm
U7: ADC1283; TSSOP-16_4.4x5mm_P0.65mm
U8: MPU-6050; InvenSense_QFN-24_4x4mm_P0.5mm

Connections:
+3.3V: C4.2, C18.1, C19.1, C21.2, JP2.3 (B), U7.2 (AVCC), U7.13 (DVCC), U8.8 (VLOGIC), U8.13 (VDD); also elsewhere on the board
AIN_0: U7.4 (IN0); also elsewhere on the board
AIN_1: U7.5 (IN1); also elsewhere on the board
AIN_2: U7.6 (IN2); also elsewhere on the board
AIN_3: U7.7 (IN3); also elsewhere on the board
AIN_4: TP4.1, U7.8 (IN4)
AIN_5: TP3.1, U7.9 (IN5)
AIN_6: U7.10 (IN6)
AIN_7: U7.11 (IN7)
ALOG_CS: U7.1 (~CS); also elsewhere on the board
BOOT0: U8.23 (SCL); also elsewhere on the board
GND: C4.1, C18.2, C19.2, C20.2, C21.1, C22.2, JP2.1 (A), U7.3 (AGND), U7.12 (DGND), U8.1 (CLKIN), U8.18 (GND); also elsewhere on the board
I2C1_SDA: U8.24 (SDA); also elsewhere on the board
MPU_SYNC: U8.11 (FSYNC); also elsewhere on the board
unnamed: JP2.2 (C), U8.9 (AD0)
unnamed: C20.1, U8.20 (CPOUT)
unnamed: C22.1, U8.10 (REGOUT)
SPI2_MISO: U7.14 (DIN); also elsewhere on the board
SPI2_MOSI: U7.15 (DOUT); also elsewhere on the board
SPI2_SCK: U7.16 (SCLK); also elsewhere on the board

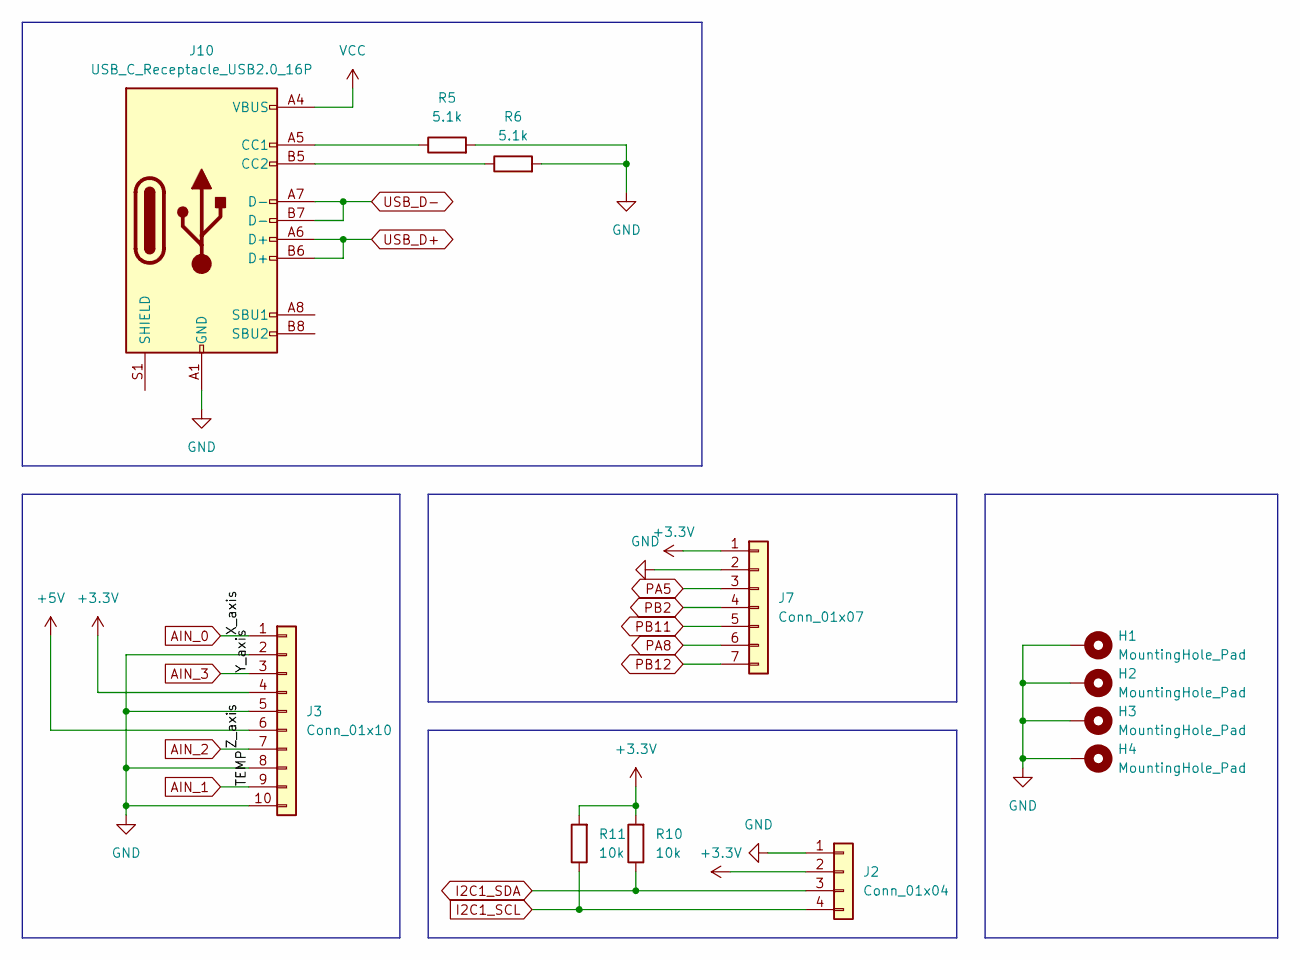
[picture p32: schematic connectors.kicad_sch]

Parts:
H1, H2, H3, H4: MountingHole_Pad; MountingHole_2.7mm_M2.5_DIN965_Pad
J2: Conn_01x04; JST_SH_SM04B-SRSS-TB_1x04-1MP_P1.00mm_Horizontal
J3: Conn_01x10; AMPHENOL_10132797-011100LF
J7: Conn_01x07; PinHeader_1x07_P2.54mm_Vertical
J10: USB_C_Receptacle_USB2.0_16P; USB_C_Receptacle_GCT_USB4105-xx-A_16P_TopMnt_Horizontal
R5, R6: 5.1k; R_0805_2012Metric
R10, R11: 10k; R_0805_2012Metric

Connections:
+3.3V: J2.2, J3.4, J7.1, R10.2, R11.2; also elsewhere on the board
+5V: J3.6
AIN_0: J3.1; also elsewhere on the board
AIN_1: J3.9; also elsewhere on the board
AIN_2: J3.7; also elsewhere on the board
AIN_3: J3.3; also elsewhere on the board
BOOT0: J2.4, R11.1; also elsewhere on the board
GND: H1.1, H2.1, H3.1, H4.1, J2.1, J3.2, J3.5, J3.8, J3.10, J3.SH1, J3.SH2, J7.2, J10.A1 (GND), J10.A12 (GND), J10.B1 (GND), J10.B12 (GND), R5.2, R6.2; also elsewhere on the board
I2C1_SDA: J2.3, R10.1; also elsewhere on the board
unnamed: J10.A5 (CC1), R5.1
unnamed: J10.B5 (CC2), R6.1
PA5: J7.3; also elsewhere on the board
PA8: J7.6; also elsewhere on the board
PB2: J7.4; also elsewhere on the board
PB11: J7.5; also elsewhere on the board
PB12: J7.7; also elsewhere on the board
USB_D+: J10.A6 (D+), J10.B6 (D+); also elsewhere on the board
USB_D-: J10.A7 (D-), J10.B7 (D-); also elsewhere on the board
VCC: J10.A4 (VBUS), J10.A9 (VBUS), J10.B4 (VBUS), J10.B9 (VBUS); also elsewhere on the board

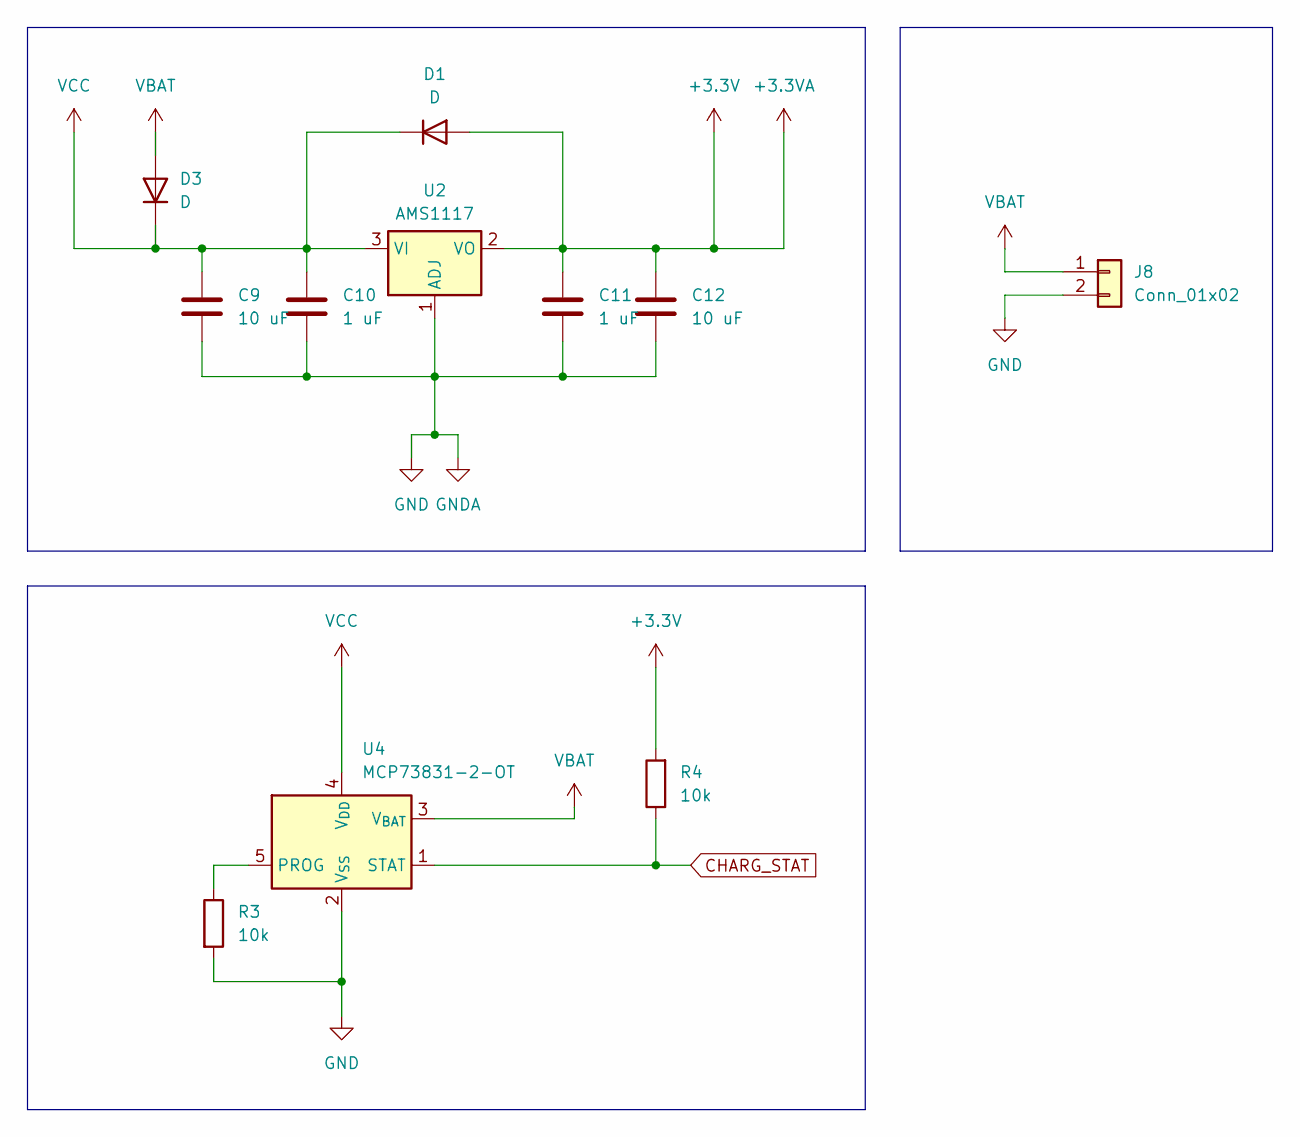
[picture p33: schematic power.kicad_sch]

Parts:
C9: 10 uF; CP_Radial_D4.0mm_P2.00mm
C10, C11: 1 uF; C_0805_2012Metric
C12: 10 uF; C_1206_3216Metric
D1, D3: D; D_SOD-123
J8: Conn_01x02; JST_PH_S2B-PH-SM4-TB_1x02-1MP_P2.00mm_Horizontal
R3, R4: 10k; R_0805_2012Metric
U2: AMS1117; SOT-89-3
U4: MCP73831-2-OT; SOT-23-5

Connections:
+3.3V: C11.1, C12.1, D1.2 (A), R4.2, U2.2 (VO); also elsewhere on the board
CHARG_STAT: R4.1, U4.1 (STAT); also elsewhere on the board
GND: C9.2, C10.2, C11.2, C12.2, J8.2, J8.MP, R3.2, U2.1 (ADJ), U4.2 (V_{SS}); also elsewhere on the board
unnamed: R3.1, U4.5 (PROG)
VBAT: D3.2 (A), J8.1, U4.3 (V_{BAT})
VCC: C9.1, C10.1, D1.1 (K), D3.1 (K), U2.3 (VI), U4.4 (V_{DD}); also elsewhere on the board

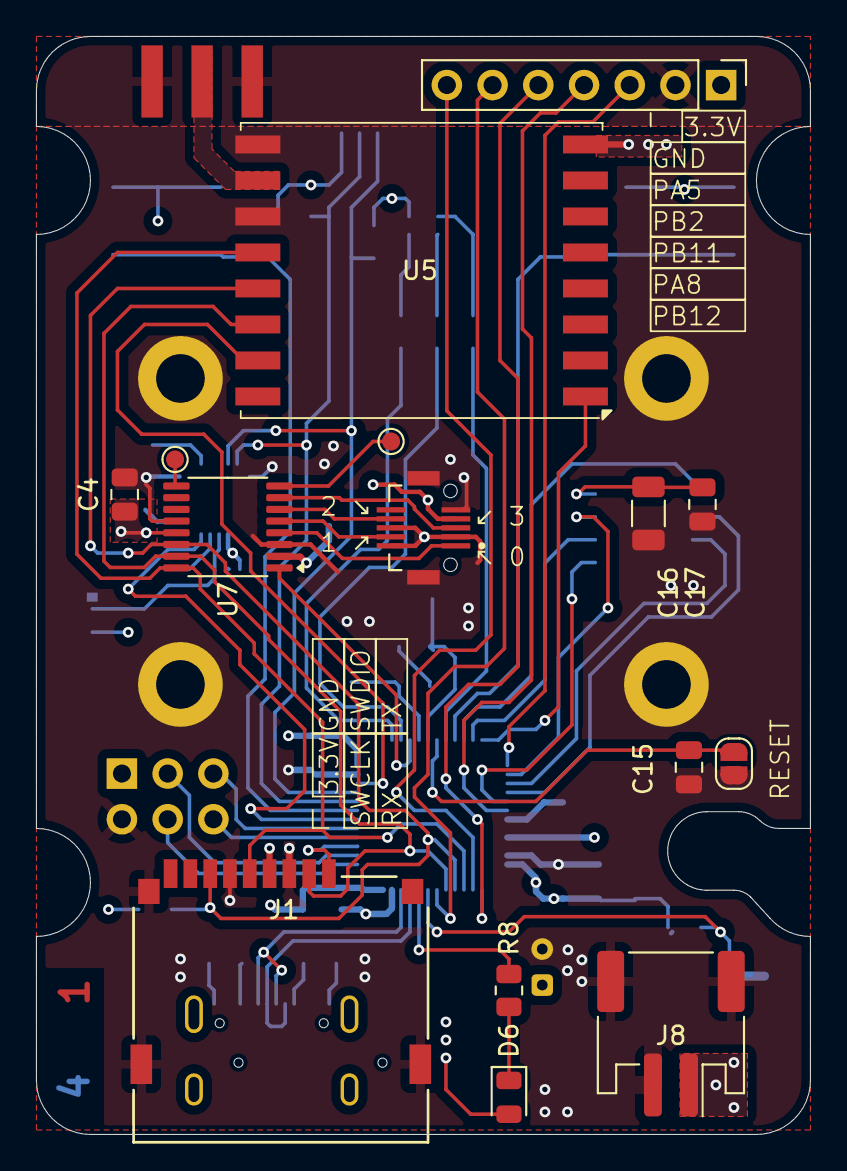
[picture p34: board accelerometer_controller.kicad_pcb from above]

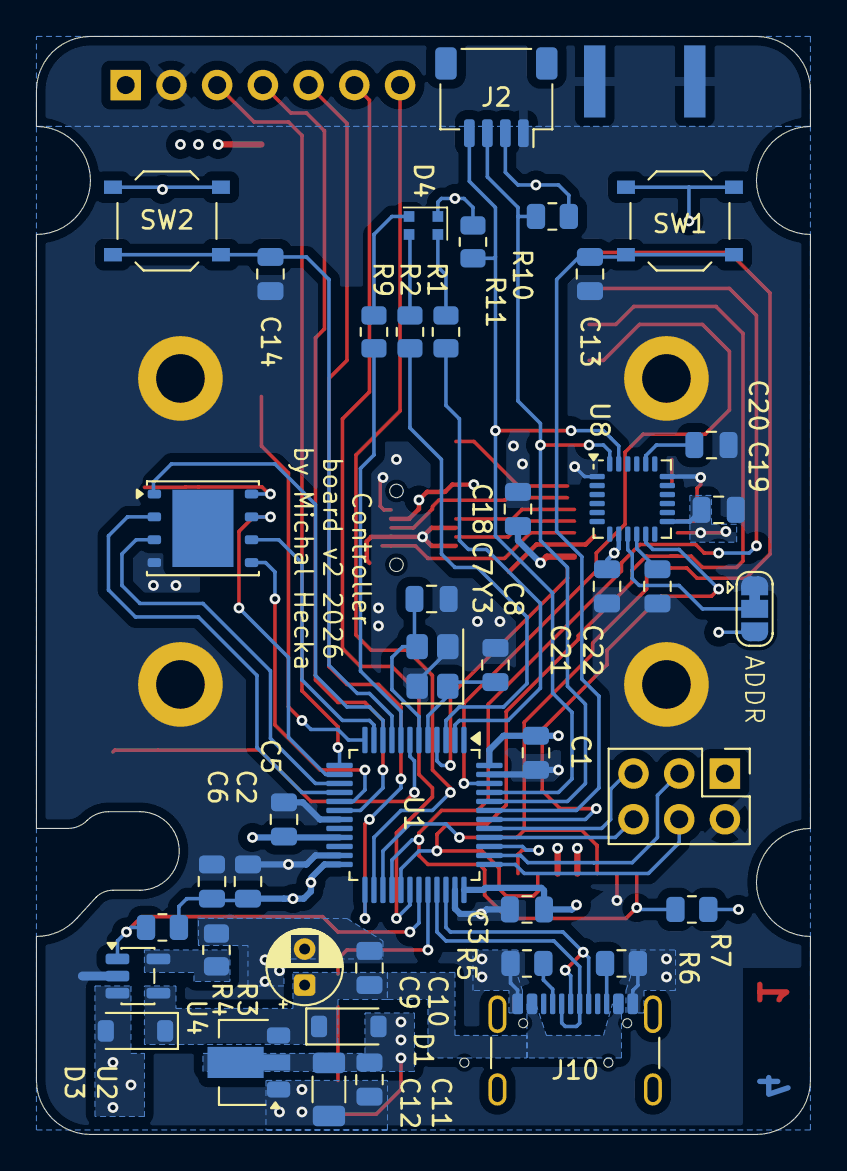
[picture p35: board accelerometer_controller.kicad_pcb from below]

Board: 4 copper layers, 43.0 x 61.0 mm, 63 parts (43 on the bottom side), 58 nets.

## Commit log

2026-08-23 Initial commit of the readme, design and the v2 pcb
    [Casing.FCStd, Light_diffuser-Body.step, Light_diffuser.FCStd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]
2026-08-23 Fixed sensor casing model view
